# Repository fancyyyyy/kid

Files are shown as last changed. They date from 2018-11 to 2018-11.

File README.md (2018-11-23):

# kid
6hp trianlge-core vco

No transistor matching, tune it in the same way as you would every other expo converter of this style. There's lots of info on how to tune an analogue oscillator that's better written than I will ever do.

Trim the sine by ear, or use a signal analyser to trim out the 3rd harmonic with R27. R29 has minimal effect, so don't drive yourself mad with it.

The saw trims trim out the bump in the saw, plug it into a scope and trim until you're happy.

Seat the tempco in contact with the sot363-6 transistor pair and stick some thermal paste on top of them.

This is largely an adaptation of the stroh pico vco with some changes to the expo converter.

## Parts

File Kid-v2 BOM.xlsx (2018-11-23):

Qty | Value | Package | Index | Description | Mouser / Thonk | Notes
Resistors
1 | 10R | R0603 | R6 | RESISTOR, American symbol
4 | 330R | R0603 | R12 R21 R31 R41 | RESISTOR, American symbol
2 | 470R | R0603 | R44 R45 | RESISTOR, American symbol
1 | 510R | R0603 | R22 | RESISTOR, American symbol
3 | 1K | R0603 | R20 R25 R28 | RESISTOR, American symbol
1 | 1K TEMPCO | R0805 | R11 | RESISTOR, American symbol | LT732ATTD102J3600 | Use a normal 0805 1k if u dgaf about western tuning
1 | 4.3k | R0603 | R48 | RESISTOR, American symbol
1 | 4.7k | R0603 | R23 | RESISTOR, American symbol
1 | 6.8k | R0603 | R24 | RESISTOR, American symbol
1 | 8.06K | R0603 | R5 | RESISTOR, American symbol
2 | 9.1K | R0603 | R34 R35 | RESISTOR, American symbol
4 | 10K | R0603 | R2 R36 R38 R40 | RESISTOR, American symbol
3 | 20K | R0603 | R30 R37 R39 | RESISTOR, American symbol
1 | 22K | R0603 | R7 | RESISTOR, American symbol
1 | 24k | R0603 | R47 | RESISTOR, American symbol
1 | 51k | R0603 | R10 | RESISTOR, American symbol
1 | 56k | R0603 | R26 | RESISTOR, American symbol
1 | 91k | R0603 | R9 | RESISTOR, American symbol
7 | 100K | R0603 | R1 R3 R4 R13 R14 R42 R43 | RESISTOR, American symbol
3 | 1M | R0603 | R16 R17 R46 | RESISTOR, American symbol
2 | 2.2M | R0603 | R15 R19 | RESISTOR, American symbol
Capacitors
1 | 33p | C0603 | C5 | CAPACITOR, European symbol
1 | 330p | C0603 | C6 | CAPACITOR, European symbol
1 | 1n | C0603 | C1 | CAPACITOR, European symbol
1 | 2.2n | C0603 | C3 | CAPACITOR, European symbol |  | NPO / COG timing cap
15 | 100n | C0603 | C4 C7 C8 C11 C12 C13 C14 C15 C16 C17 C18 C19 C20 C21 C22 | CAPACITOR, European symbol
2 | 470n | 0603-CAP | C2, C46 | CAPACITOR, European symbol
1 | 4.7u | PANASONIC_B | C23 | POLARIZED CAPACITOR, American symbol |  | AC coupling cap for linfm, bridge this if you don't care
2 | 22u | PANASONIC_C | C9, C10 | POLARIZED CAPACITOR, American symbol
Hardware
1 | 500R | RTRIM3296W | R27 | Trimm resistor | Tayda
2 | 2k | RTRIM3296W | R32 R33 | Trimm resistor | Tayda
1 | 10k | RTRIM3296W | R8 | Trimm resistor | Tayda
1 | 25k | RTRIM3296W | R29 | Trimm resistor | Tayda
1 | 100k | RTRIM3296W | R18 | Trimm resistor | Tayda
1 | LED3MM | LED3MM | LED1 |  | https://www.mouser.co.uk/ProductDetail/604-WP937EGW | bi-colour if you want
1 | EURO_POWER_HEADER | EURO_PWR_HEADER_LOCK | SV2 | Power Header
1 | SUBMINI_SPDT ON-ON | SUBMINI_TOGGLE | SW1 |  | https://www.thonk.co.uk/shop/sub-mini-toggle-switches/ | ON-ON
1 | SUBMINI_SPDT ON-OFF-ON | SUBMINI_TOGGLE | SW2 |  | https://www.thonk.co.uk/shop/sub-mini-toggle-switches/ | ON-OFF-ON
8 | THONKICONNNEW | WQP-PJ301M-12_JACK | U1, U2, U3, U4, U5, U6, U7, U8 | 3.5mm socket for Eurorack modular synths | https://www.thonk.co.uk/shop/thonkiconn/
2 |  | 9MM_SNAP-IN_POT | VR1, VR2 | 9mm vertical snap-in pot, Alpha / Panasonic style | https://www.thonk.co.uk/shop/alpha-9mm-pots/ | Course & Fine
2 |  | 9MM_TALL-TRIM-POT | VR3, VR4 |  | https://www.thonk.co.uk/product-category/parts/pot/9mm/9mm-trimmer-pots/ | FM Attenuation
Semi
1 | 1N4148 | SOD-323 | D1 | Diode | 1N4148WS
1 | LM13700M | SO16 | IC3 | Dual OTA with buffers
2 | LM4040C10 | SOT23-3 | IC8 IC13 | PRECISION MICROPOWER SHUNT VOLTAGE REFERENCE | LM4040CIM3-10.0/NOPB | The higher class regulators you use, the better the octave switch is - C is fine
1 | MOSFET-N | SOT23-3 | Q10 |  | DMN3023L-7 | Reverse power protection, there are cheaper options if you wanna look - none in stock when I built mine, so I used these
1 | MOSFET-P | SOT23-3 | Q8 |  | DMP3099L-7 | Don't use diodes, for reverse protection - the drop is too much for 10v reg
1 | MMBFJ310 | SOT23-3 | Q3 | N-Channel JFETs | MMBFJ310 | Other fets could work here
5 | TL072D | SO08 | IC1, IC2, IC5, IC6, IC7 | OP AMP
1 | TL331 | SOT23-5 | IC9 | SINGLE DIFFERENTIAL COMPARATOR | TL331KDBVR
1 | mmbt3904 | SOT23-3 | Q2 | Transistor NPN | MMBT3904-7-F
1 | pmp5201 | SOT-363-6 | Q1 |  | PMP5201Y,115 | Put in contact with the 1k tempco, smear some thermal paste on top. You could try a dab of hot glue on top of that to insulate the whole thing

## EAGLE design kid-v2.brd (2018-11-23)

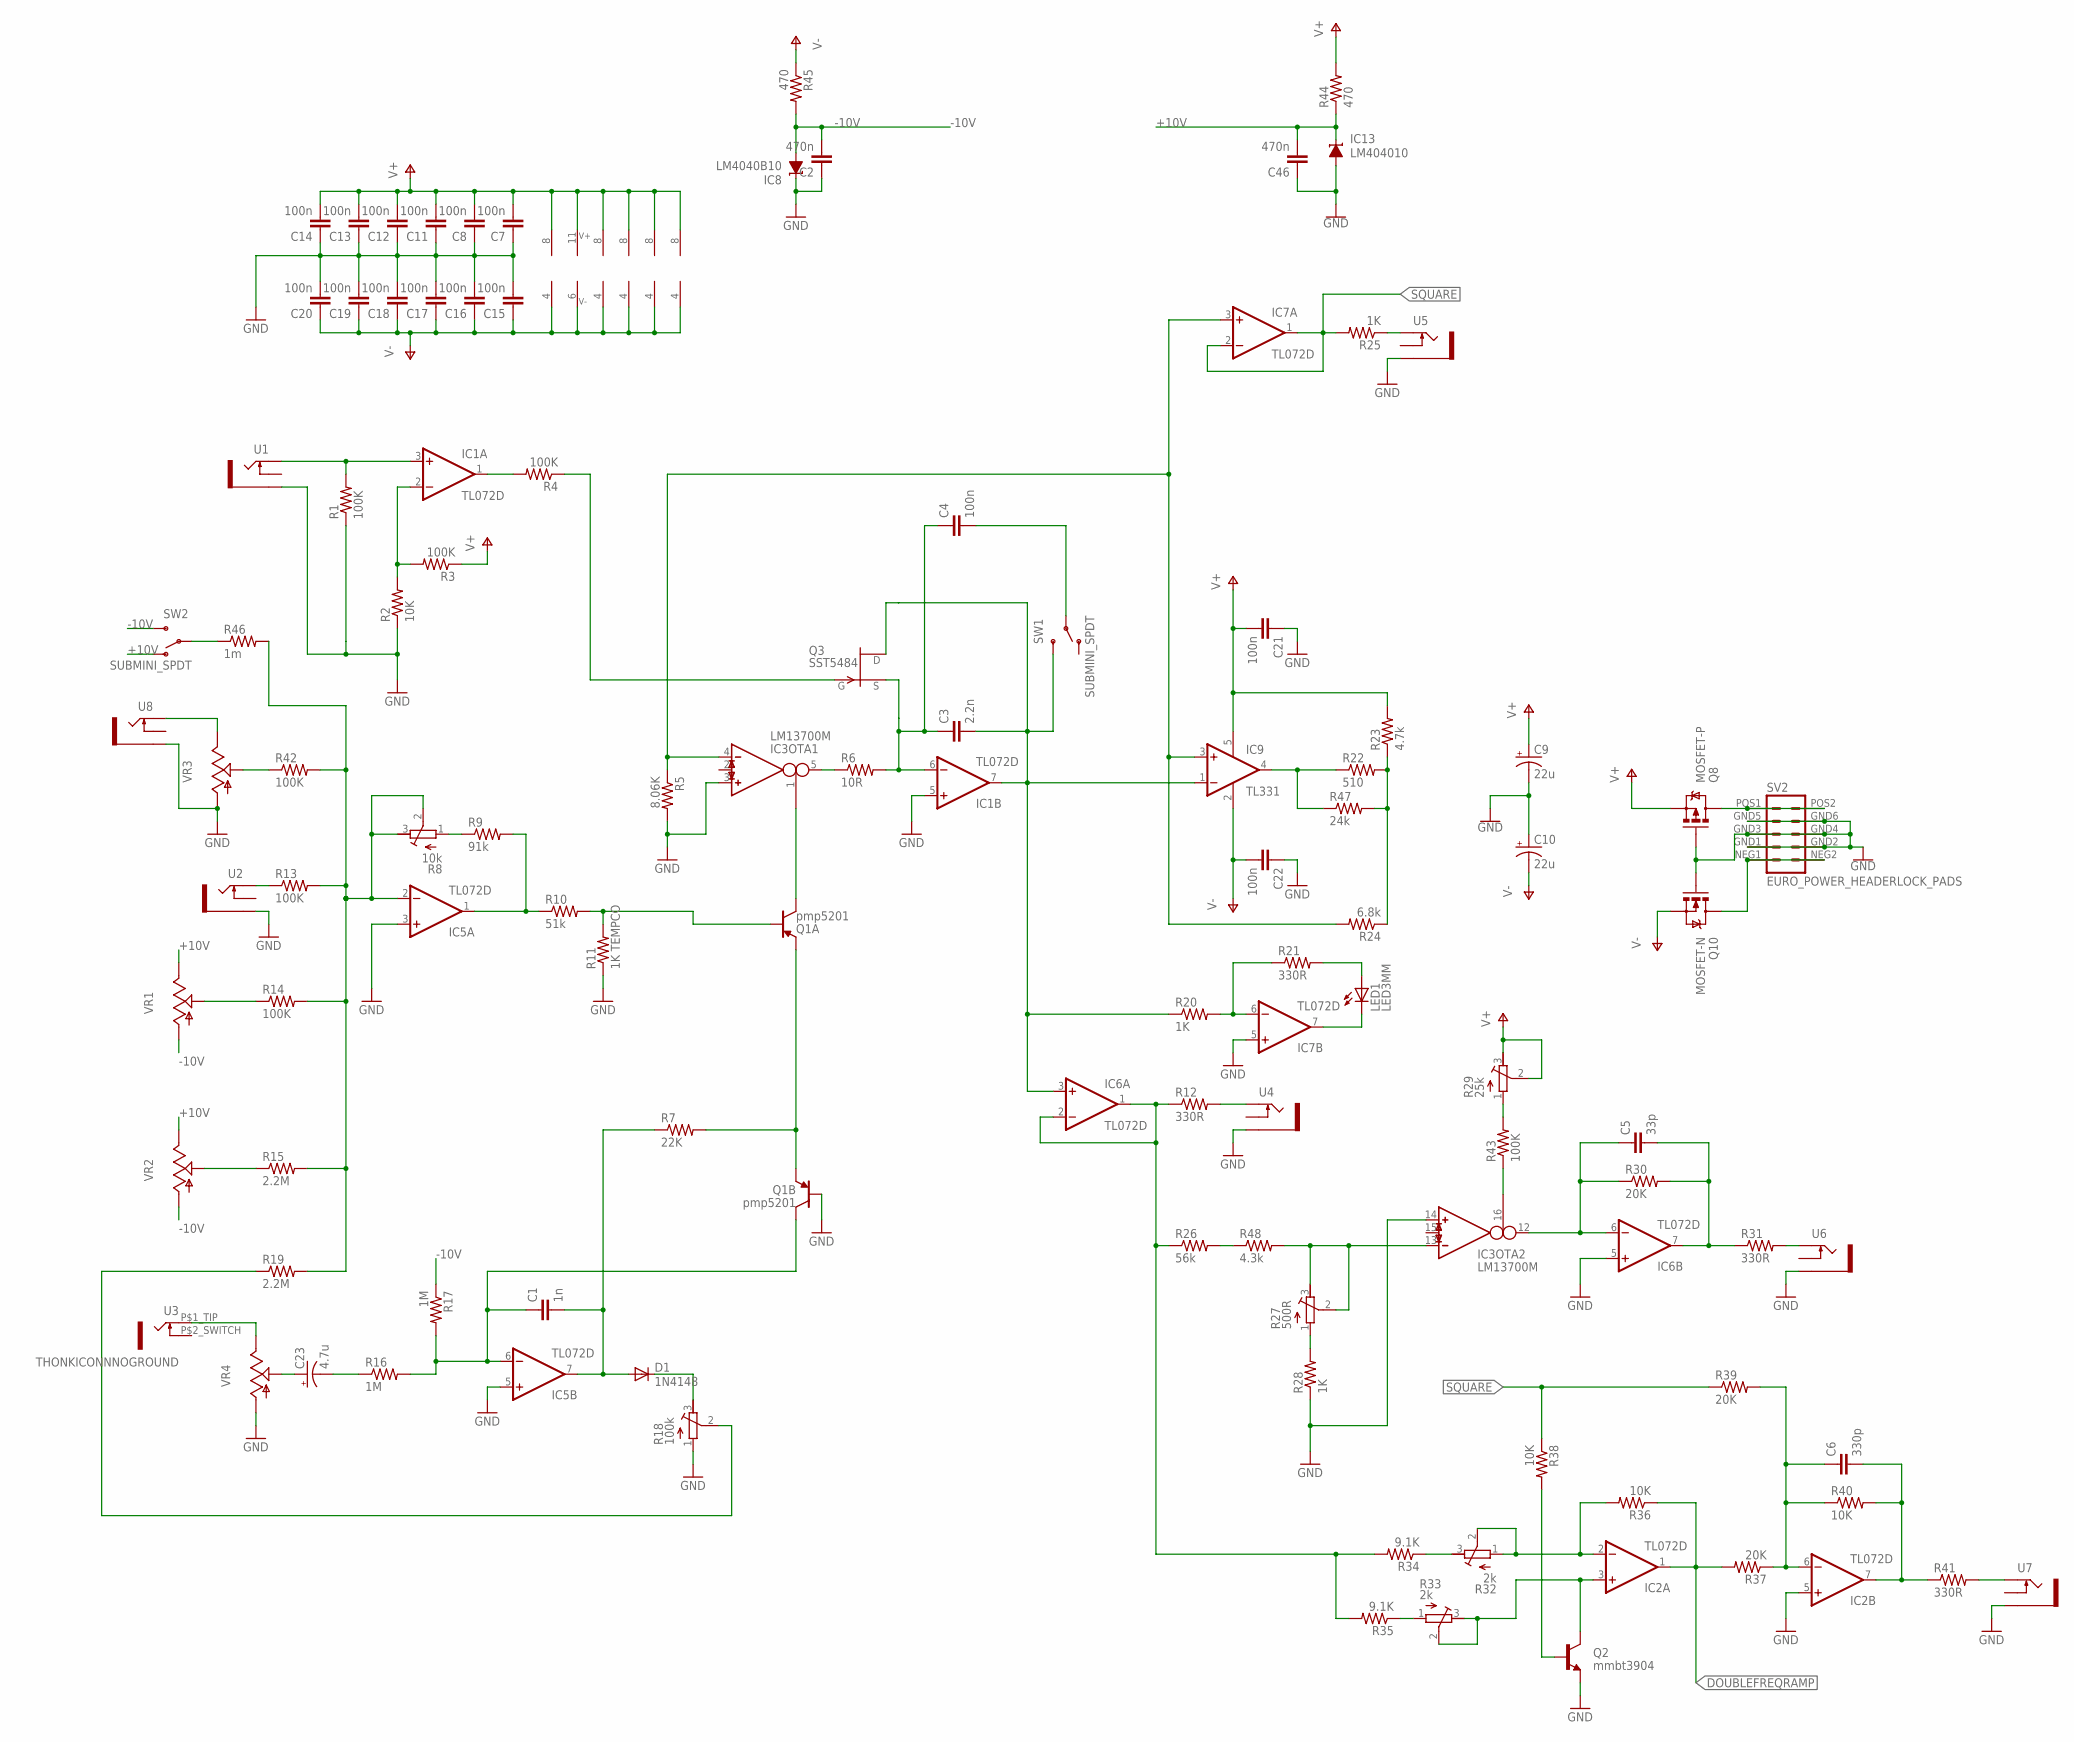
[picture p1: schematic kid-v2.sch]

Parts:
C1: 1n; C0603
C2, C46: 470n; 0603-CAP
C3: 2.2n; C0603
C4, C7, C8, C11, C12, C13, C14, C15, C16, C17, C18, C19, C20, C21, C22: 100n; C0603
C5: 33p; C0603
C6: 330p; C0603
C9, C10: 22u; PANASONIC_C
C23: 4.7u; PANASONIC_B
D1: 1N4148; SOD-323
IC1, IC2, IC5, IC6, IC7: TL072D; SO08
IC3: LM13700M; SO16
IC8: LM4040B10; DBZ_R-PDSO-G3
IC9: TL331; DBV-R-PDSO-G5
IC13: LM404010; DBZ_R-PDSO-G3
LED1: LED3MM
Q1: pmp5201; SOT363
Q2: mmbt3904; SOT23
Q3: SST5484; SOT23
Q8: MOSFET-P; SOT23-3
Q10: MOSFET-N; SOT23-3
R1, R3, R4, R13, R14, R42, R43: 100K; R0603
R2, R36, R38, R40: 10K; R0603
R5: 8.06K; R0603
R6: 10R; R0603
R7: 22K; R0603
R8: 10k; RTRIM3296W
R9: 91k; R0603
R10: 51k; R0603
R11: 1K TEMPCO; R0805
R12, R21, R31, R41: 330R; R0603
R15, R19: 2.2M; R0603
R16, R17: 1M; R0603
R18: 100k; RTRIM3296W
R20, R25, R28: 1K; R0603
R22: 510; R0603
R23: 4.7k; R0603
R24: 6.8k; R0603
R26: 56k; R0603
R27: 500R; RTRIM3296W
R29: 25k; RTRIM3296W
R30, R37, R39: 20K; R0603
R32, R33: 2k; RTRIM3296W
R34, R35: 9.1K; R0603
R44: 470; 0603-RES
R45: 470; R0603
R46: 1m; R0603
R47: 24k; R0603
R48: 4.3k; R0603
SV2: EURO_POWER_HEADERLOCK_PADS; EURO_PWR_HEADER_LOCK
SW1, SW2: SUBMINI_SPDT; SUBMINI_TOGGLE
U1, U2, U4, U5, U6, U7, U8: THONKICONNNEW; WQP-PJ301M-12_JACK
U3: THONKICONNNOGROUND
VR1, VR2, VR3, VR4: 9MM_SNAP-IN_POT_; 9MM_SNAP-IN_POT

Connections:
+10V: C46.2, IC13.1 (C), R44.1, SW2.1 (O), VR1.3 (E), VR2.3 (E)
-10V: C2.2, IC8.2 (A), R17.1, R45.2, SW2.3 (S), VR1.1 (A), VR2.1 (A)
DOUBLEFREQRAMP: IC2.1 (OUT), R36.1, R37.2
GND: C2.1, C7.1, C8.1, C9.-, C10.+, C11.1, C12.1, C13.1, C14.1, C15.2, C16.2, C17.2, C18.2, C19.2, C20.2, C21.1, C22.1, C46.1, IC1.5 (+IN), IC2.5 (+IN), IC3.3 (IN_P), IC3.14 (IN_P), IC5.3 (+IN), IC5.5 (+IN), IC6.5 (+IN), IC7.5 (+IN), IC8.1 (C), IC13.2 (A), Q1.P$2 (B), Q2.2 (E), Q8.1 (G), Q10.1 (G), R1.1, R2.1, R5.2, R11.1, R18.1 (A), R28.1, SV2.GND1 (4), SV2.GND2 (3), SV2.GND3 (6), SV2.GND4 (5), SV2.GND5 (8), SV2.GND6 (7), U1.P$3_SLEEVE (SLEEVE), U2.P$3_SLEEVE (SLEEVE), U4.P$3_SLEEVE (SLEEVE), U5.P$3_SLEEVE (SLEEVE), U6.P$3_SLEEVE (SLEEVE), U7.P$3_SLEEVE (SLEEVE), U8.P$3_SLEEVE (SLEEVE), VR3.1 (A), VR4.1 (A)
unnamed: IC1.3 (+IN), R1.2, U1.P$1_TIP (TIP)
unnamed: R26.2, R48.1
unnamed: IC1.2 (-IN), R2.2, R3.2
unnamed: IC3.4 (IN_N), IC7.3 (+IN), IC9.3 (+IN), R5.1, R24.2
unnamed: IC1.1 (OUT), R4.2
unnamed: IC3.5 (OUT), R6.1
unnamed: C3.1, C4.1, IC1.6 (-IN), Q3.2 (S), R6.2
unnamed: IC3.1 (I_BIAS), Q1.P$6 (C)
unnamed: Q1.P$4 (E), Q1.P$5 (E), R7.2
unnamed: Q1.P$1 (B), R10.2, R11.2
unnamed: IC5.1 (OUT), R9.2, R10.1
unnamed: R15.1, VR2.2 (S)
unnamed: Q3.3 (G), R4.1
unnamed: R14.1, VR1.2 (S)
unnamed: R13.1, U2.P$1_TIP (TIP)
unnamed: C1.1, IC5.6 (-IN), Q1.P$3 (C), R16.2, R17.2
unnamed: C23.+, VR4.2 (S)
unnamed: C23.-, R16.1
unnamed: C1.2, D1.2 (A), IC5.7 (OUT), R7.1
unnamed: D1.1 (C), R18.3 (E)
unnamed: R18.2 (S), R19.1
unnamed: U3.P$1_TIP (2), VR4.3 (E)
unnamed: C3.2, IC1.7 (OUT), IC6.3 (+IN), IC9.1 (-IN), Q3.1 (D), R20.1, SW1.3 (S)
unnamed: C4.2, SW1.COM (COMMON)
unnamed: IC3.13 (IN_N), R27.2 (S), R27.3 (E), R48.2
unnamed: IC6.1 (OUT), IC6.2 (-IN), R12.1, R26.1, R34.2, R35.2
unnamed: R12.2, U4.P$1_TIP (TIP)
unnamed: IC7.7 (OUT), LED1.K (C)
unnamed: IC7.6 (-IN), R20.2, R21.1
unnamed: LED1.A, R21.2
unnamed: R25.1, U5.P$1_TIP (TIP)
unnamed: IC5.2 (-IN), R8.2 (S), R8.3 (E), R13.2, R14.2, R15.2, R19.2, R42.2, R46.2
unnamed: R22.2, R23.1, R24.1, R47.2
unnamed: R27.1 (A), R28.2
unnamed: U8.P$1_TIP (TIP), VR3.3 (E)
unnamed: C5.1, IC3.12 (OUT), IC6.6 (-IN), R30.1
unnamed: R29.1 (A), R43.2
unnamed: R32.3 (E), R34.1
unnamed: R33.1 (A), R35.1
unnamed: C5.2, IC6.7 (OUT), R30.2, R31.1
unnamed: IC2.3 (+IN), Q2.3 (C), R33.2 (S), R33.3 (E)
unnamed: R31.2, U6.P$1_TIP (TIP)
unnamed: IC2.2 (-IN), R32.1 (A), R32.2 (S), R36.2
unnamed: Q2.1 (B), R38.2
unnamed: C6.2, IC2.7 (OUT), R40.2, R41.1
unnamed: R41.2, U7.P$1_TIP (TIP)
unnamed: IC3.16 (I_BIAS), R43.1
unnamed: R42.1, VR3.2 (S)
unnamed: R46.1, SW2.COM (COMMON)
unnamed: IC9.4 (OUT), R22.1, R47.1
unnamed: Q8.3 (D), SV2.POS1 (10), SV2.POS2 (9)
unnamed: R8.1 (A), R9.1
unnamed: Q10.3 (D), SV2.NEG1 (2), SV2.NEG2 (1)
REGSAW: C6.1, IC2.6 (-IN), R37.1, R39.2, R40.1
SQUARE: IC7.1 (OUT), IC7.2 (-IN), R25.2, R38.1, R39.1
V+: C7.2, C8.2, C9.+, C11.2, C12.2, C13.2, C14.2, C21.2, IC1.8 (V+), IC2.8 (V+), IC3.11 (V+), IC5.8 (V+), IC6.8 (V+), IC7.8 (V+), IC9.5 (V+), Q8.2 (S), R3.1, R23.2, R29.2 (S), R29.3 (E), R44.2
V-: C10.-, C15.1, C16.1, C17.1, C18.1, C19.1, C20.1, C22.2, IC1.4 (V-), IC2.4 (V-), IC3.6 (V-), IC5.4 (V-), IC6.4 (V-), IC7.4 (V-), IC9.2 (GND), Q10.2 (S), R45.1

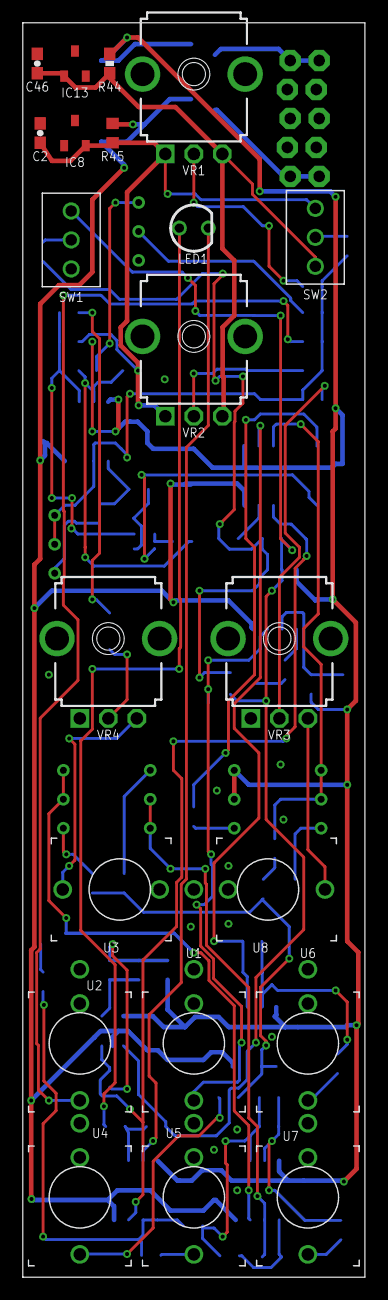
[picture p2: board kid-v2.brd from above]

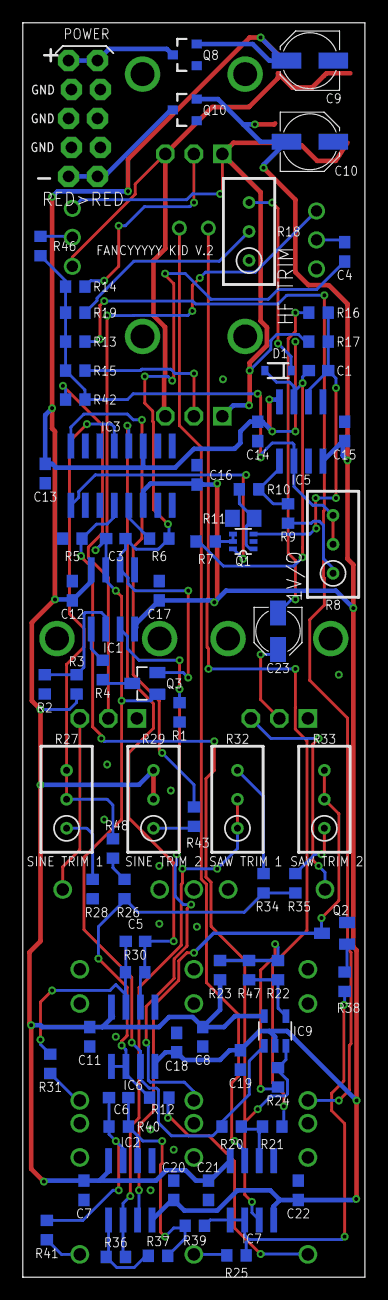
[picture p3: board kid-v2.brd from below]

Board: 2 copper layers, 30.0 x 110.0 mm, 103 parts (82 on the bottom side), 61 nets.

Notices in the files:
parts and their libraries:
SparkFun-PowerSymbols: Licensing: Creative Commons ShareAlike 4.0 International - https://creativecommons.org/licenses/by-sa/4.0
